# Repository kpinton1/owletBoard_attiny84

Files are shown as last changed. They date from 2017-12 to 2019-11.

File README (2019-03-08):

Readme

Documentation including BOM and bootloader instructions, component arrangement, and Users guide are located in documentation. 

PCB schematics and layout are in hardware(oregon) and hardware(owl)

Latest design files are fab_v3.zip for both Owl and Oregon shapes. 

We use Micronucleus bootloader which uses V-USB. License file included.

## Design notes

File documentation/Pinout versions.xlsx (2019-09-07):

Arduino Pin Number | OregonBoard v3 | owlBoard v5.0c | owlBoard v6 | OregonBoard v4 | Logic
0 | Right Eye LED | Right Eye LED | Portland Metro LED | Portland Metro LED | ‘1’ = ON; ‘0’ = OFF
1 | Switch 1 | Switch 1 | Switch 1 | Switch 1 | PUSHED = ‘1’; ELSE = ‘0’
2 | Switch 2 | Switch 2 | Switch 2 | Switch 2 | PUSHED = ‘1’; ELSE = ‘0’
3 | Red RGB | Pinout to header | Red RGB | Pinout to header | ‘0’ = ON; ‘1’ = OFF
4 | Blue RGB | Pinout to header | Blue RGB | Pinout to header | ‘0’ = ON; ‘1’ = OFF
5 | Green RGB | Pinout to header | Green RGB | Pinout to header | ‘0’ = ON; ‘1’ = OFF
6 | Pinout to header | Red RGB | Pinout to header | Red RGB | ‘0’ = ON; ‘1’ = OFF
7 | Pinout to header | Blue RGB | Pinout to header | Blue RGB | ‘0’ = ON; ‘1’ = OFF
8 | Pinout to header | Green RGB | Pinout to header | Green RGB | ‘0’ = ON; ‘1’ = OFF

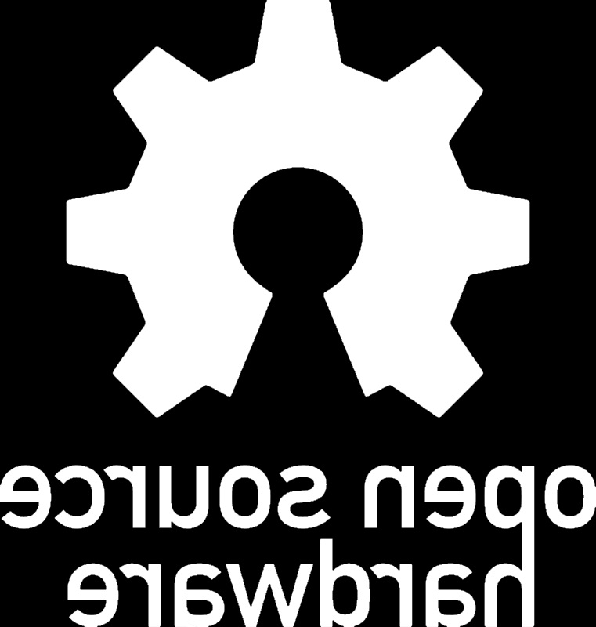
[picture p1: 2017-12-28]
images/bw_oshw.jpg

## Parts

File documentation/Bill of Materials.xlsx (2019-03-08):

Component | Footprint | Quantity | Reference Designator | Supplier | Vendor |  |  | Notes
RGB LED (Common Anode) | 5mm LED | 1 | D3 | Any 5mm Common Anode LED | Any | 0.1
LED (Always use red for Portland Metro LED) | 3mm LED | 2 | D1, D2 | Any 3mm LED | Any | 0.1
Linear regulator AMS1117-3.3 | SOT-223 | 1 | U3 | AMS1117-3.3 | Any | 0.1 |  | Can sub with LM1117-3.3 if need US supplier
Ceramic capacitor 1.0 UF | 5.08mm spacing | 2 | C1,C2 | Any 1uF ceramic with 5.08mm spacing | Any | 0.1
330 Ohm resistor | Through-hole | 5 | R1, R2, R12,R13,R14 | CF14JT330R | Stackpole | 0.1 | Digikey or Arrow
68 Ohm resistor | Through-hole | 2 | R8, R9 | CF14JT68R0TR | Stackpole | 0.1 | Digikey or Arrow
1.5K or 10K resistors | Through-hole | 3 | R4, R6, R7 | CF14JT10K0TR | Stackpole | 0.1 | Digikey or Arrow
USB connector type A (Owlboard Jr.) or type B (Oregon board) | Varies | 1 | J5/U4 | UJ2-BH-1-TH OR UP2-AH-1-TH | CUI | 0.54 | Digikey or Arrow | Use UJ2-BH for Oregon board Use UP2-AH-1-TH for Owl board
ATTINY84 Microcontroller | PDIP-14 | 1 | U1 | ATTINY84A-PU | Microchip | 0.99 | Digikey or Arrow | This part needs to be programmed!
Button | 6mm x 6mm | 2 | S1, S2 | 1825910-6 | TE Connectivity | 0.11 | Digikey or Arrow | Check for fit. Unsure.
Fuse | 1206 | 1 | Fuse | 0ZCH0020FF2E | Bel | 0.11 | Digikey or Arrow
USB A | N/A | 1 | N/A | Monoprice | Monoprice | 1.19 | Monoprice (https://www.monoprice.com/product?p_id=5438) | Use only for Oregon board

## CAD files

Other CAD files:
hardware(oregon)/Oregon_Outline2.dwg
hardware(oregon)/Oregon_Outline1.dwg
hardware(oregon)/Oregon_Outline3.dwg

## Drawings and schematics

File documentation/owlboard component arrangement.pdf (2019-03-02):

# Owlboard / Oregon Board Workshop

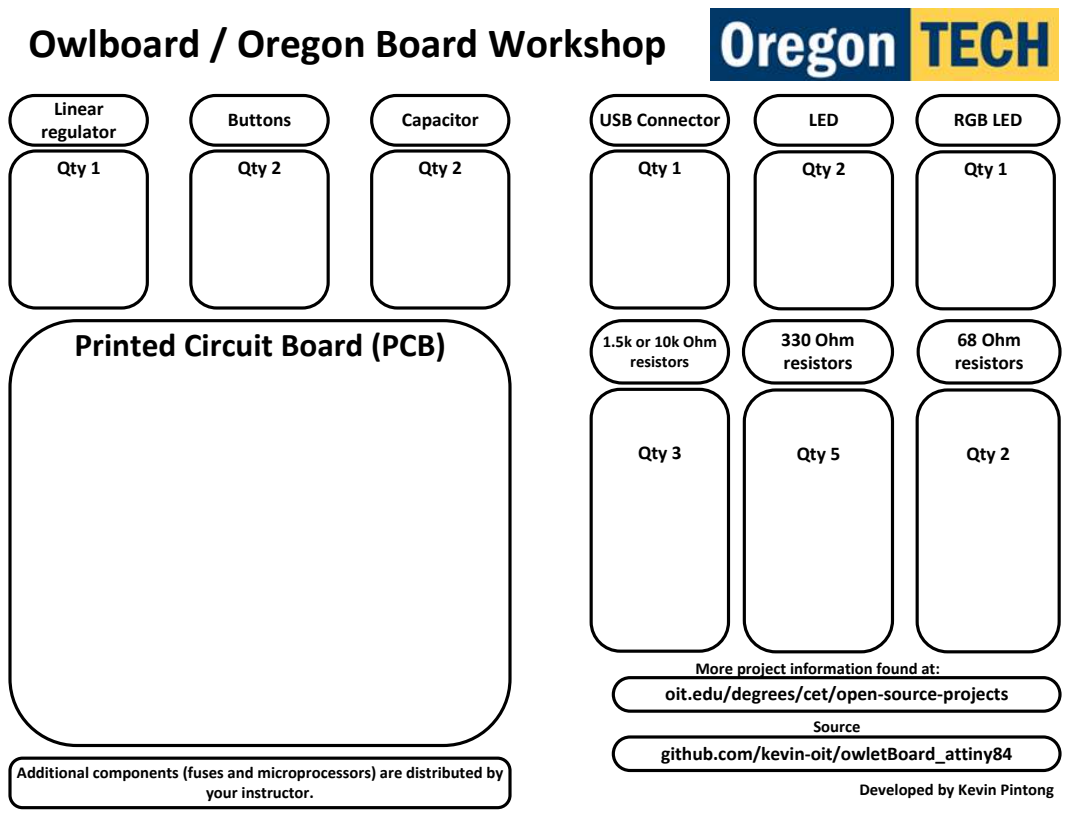
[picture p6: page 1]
Buttons; 1.5k or 10k Ohm; Qty 2; Qty 5; your instructor.; Developed by Kevin Pintong; 330 Ohm resistors; 68 Ohm resistors; Capacitor Linear; regulator; USB Connector; LED; RGB LED; Qty 1; Source; Qty 3

resistors Printed Circuit Board (PCB)

More project information found at:
oit.edu/degrees/cet/open-source-projects

github.com/kevin-oit/owletBoard_attiny84

Additional components (fuses and microprocessors) are distributed by

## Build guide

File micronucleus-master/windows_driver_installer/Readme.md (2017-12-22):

# Windows driver installation with Zadig #

Zadig is an automated windows driver installer for libusb devices. It will automatically create a driver signature, which prevents issues with unsigned drivers on Windows 10 and earlier. The latest version of Zadig can be found here: [http://zadig.akeo.ie/](http://zadig.akeo.ie/). For convenience, a copy is provided in this folder.

Please proceed as follows to install the Micronucleus driver:

1. Run Zadig_2.1.2.exe. The interface, as shown below, appears.
2. In the menu, go to *Device->Load Preset Device*.  Select micronucleus.cfg.
3. Click the "Install Driver" button.

The driver is now installed and Micronucleus should be ready to use. 

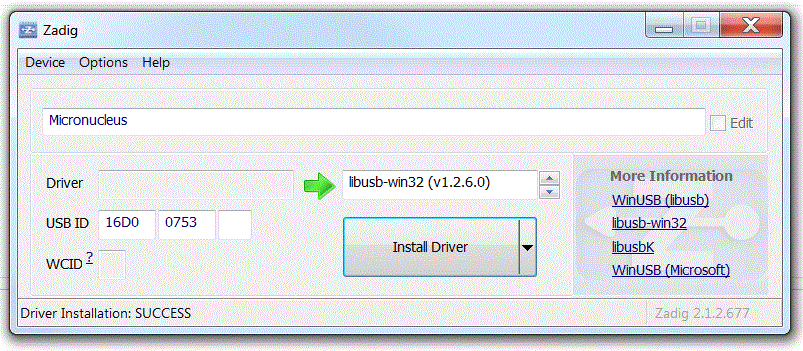
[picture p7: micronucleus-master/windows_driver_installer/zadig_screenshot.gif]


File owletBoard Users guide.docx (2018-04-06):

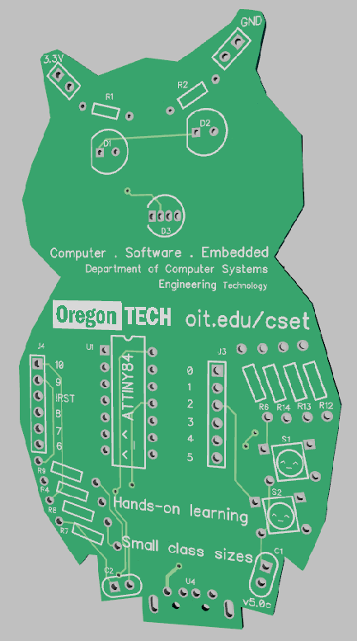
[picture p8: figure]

Oregon Institute of Technology

Owlboard Jr. v4.0 / Oregon shape board v1.0

Users Guide / Assembly Guide / Tutorials

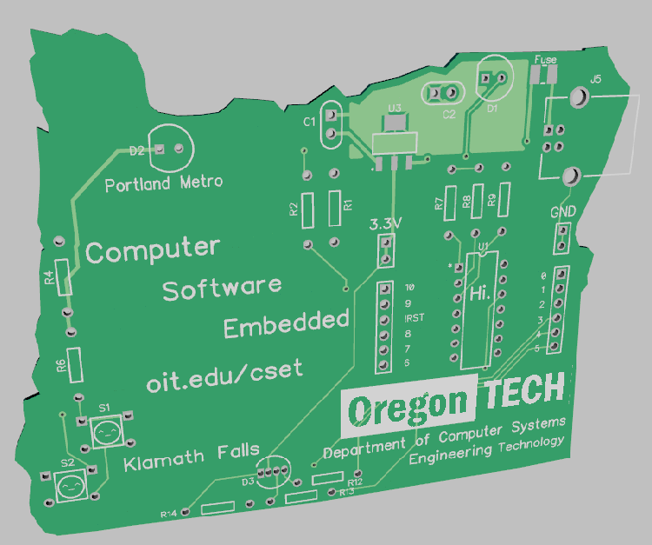
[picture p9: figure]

# Note

Portions of software and hardware design originated from Digispark, a product of Digistump. The Owlboard Jr. and Oregon Shape board are not products of Digistump. Do not contact them for any support.

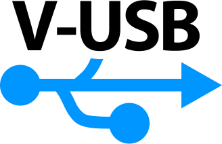
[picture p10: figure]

The USB bootloader uses V-USB, available from: https://www.obdev.at/products/vusb/index.html

# Safety and Liability

If you are participating in the soldering portion of the workshop, you must do the following:

1) Listen to and follow instructions from faculty and student assistants.
2) Wear personal protective equipment such as safety glasses.
3) Use the fume extractor to blow smoke away from you.
4) Be aware that the soldering iron is hot, and you should be careful when using it.
5) Be aware that the flux and solder fumes, while not hazardous can cause respiratory distress.
6) Wash your hands after the workshop and after handling your board.

Be aware that you are putting together a board which may be plugged into your computer. While the faculty and student assistants involved will try and make sure that the board is properly assembled, note that improperly assembled boards or improperly handled boards may cause damage to your computer.

Oregon Institute of Technology is not responsible for any damage to your personal computer.

# Owlboard Jr. v4.0 and Oregon board v1.0 Features

The owlboard Jr. and Oregon board are community outreach boards designed at Oregon Tech. They are open sourced boards using the VUSB bootloader. The software and hardware are available at the link below.

https://github.com/kevin-oit/owletBoard_attiny84

Features of the Owlboard Jr v4.0 / Oregon board v1.0

- ATTINY84 microprocessor in dip package
- One 3mm LED
- One 5mm RGB LED
- Two push buttons
- Integrated USB bootloader (V-USB)
- Built-in USB connector on Owlboard Jr.
- USB-B connector on Oregon board v1.0
- 350 mA poly fuse
- 3.3 V System voltage

ADD PICTURE OF OWLBOARD and OREGON board

# Circuit and component primer

# Assembly Instructions

Add schematic and bill of materials

# Board setup – Buttons, LEDs, and pin locations

When writing code for the Owlboard Jr. or Oregon shaped board, please use the pin numbers below in Arduino IDE.

Arduino Pin Number | Owlboard Jr. | Oregon shaped board | Logic
0 | Right Eye LED | Portland Metro LED | ‘1’ = ON; ‘0’ = OFF
1 | Switch 1 | Switch 1 | PUSHED = ‘1’; ELSE = ‘0’
2 | Switch 2 | Switch 2 | PUSHED = ‘1’; ELSE = ‘0’
3 | Red RGB | Red RGB | ‘0’ = ON; ‘1’ = OFF
4 | Blue RGB | Blue RGB | ‘0’ = ON; ‘1’ = OFF
5 | Green RGB | Green RGB | ‘0’ = ON; ‘1’ = OFF
6 | Pinout to header
7 | Pinout to header
8 | Pinout to header
9 | Pinout to header
10 | Pinout to header

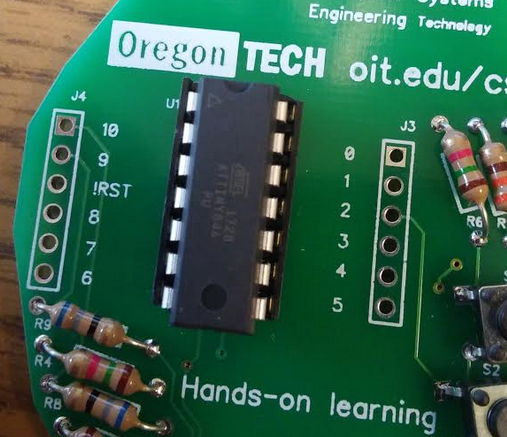
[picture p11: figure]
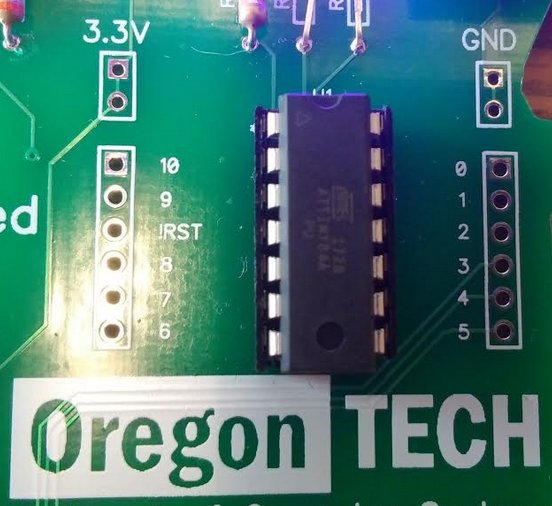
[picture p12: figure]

For example, if you wish to turn the Portland Metro or Right Eye LED on, you would need to:

1) Set pin 0 to an output

pinMode(0, OUTPUT);

2) Write in the loop logic ‘1’.

digitalWrite(0,HIGH);

If you wish to configure the button S1, you would need to:

1) Set switch 1 to input

pinMode(1, INPUT);

2) Read the button

digitalRead(1);

# Pinout of ATTINY84

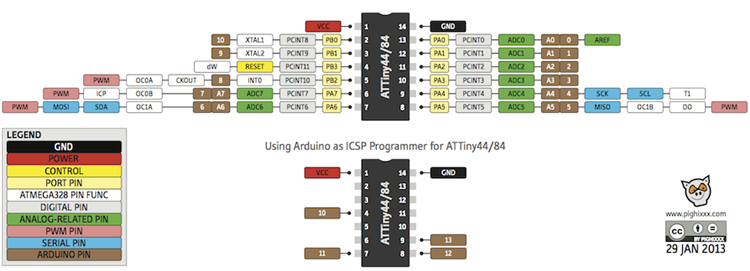
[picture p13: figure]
ATtiny84 and ATtiny84a pinout

# Installation

1. Install Arduino IDE from this link: https://www.arduino.cc/en/Main/Software
2. After Arduino IDE is installed, launch Arduino IDE.
3. Go to File > Preferences.

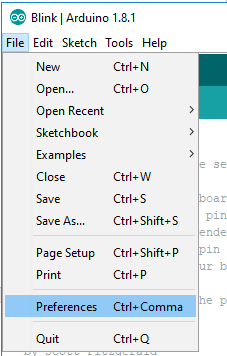
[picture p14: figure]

4. You should see the following screen.

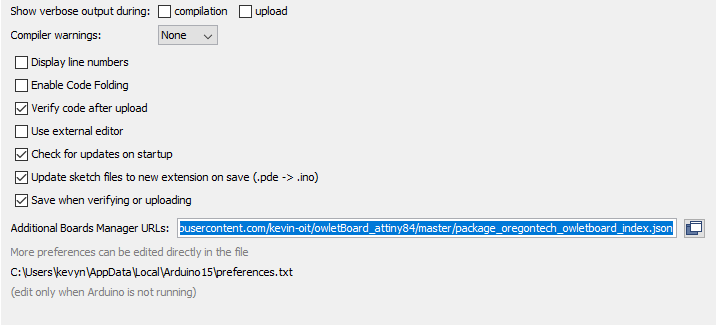
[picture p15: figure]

5. Under Additional Boards Manager URL paste this: https://raw.githubusercontent.com/kevin-oit/owletBoard_attiny84/master/package_oregontech_owletboard_index.json
6. Click OK.
7. Go to Tools > Boards > Board Manager

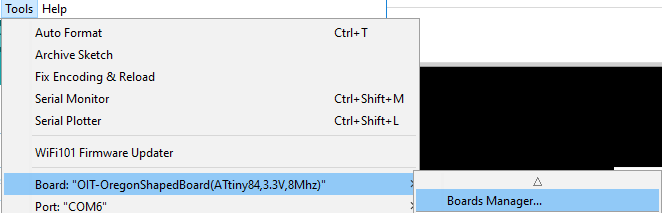
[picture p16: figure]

8. Type owl into the menu bar and you should see owlet Boards by owletBoard. Click install.
9. Download this file:

https://github.com/kevin-oit/owletBoard_attiny84/blob/master/micronucleus_for_owlboard_0.1-win.zip

10. Unzip the file.

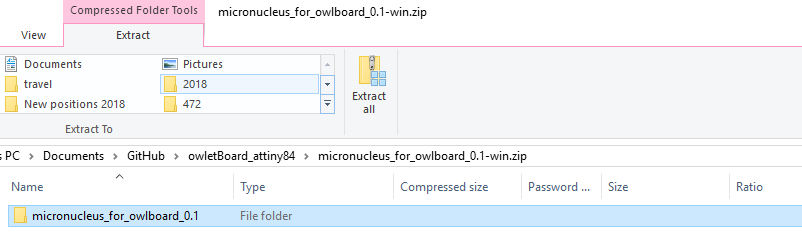
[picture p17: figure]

11. When the files are extracted, a new window will open up.
12. Navigate to the windows_driver_installer folder.
13. Double-click on zadig_2.1.2.exe. The window below should launch.

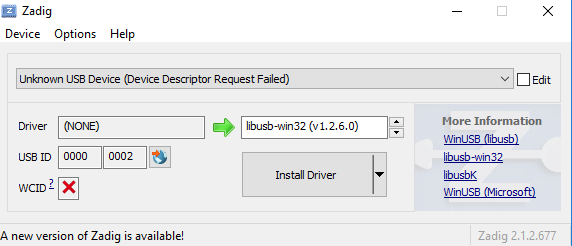
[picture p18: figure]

14. Plug your board into the computer. Within 5 seconds, switch to the unknown device and then click Install Driver. You may need to try more than once to install the driver.
15. Wait for success.

Congratulations.

You have now installed all the software required to use the Owlboard Jr. or the Oregon shape board.

# Tutorial 1: Uploading code to the board

1. Make sure you have installed the driver, Arduino IDE, and installed the board file as listed in the previous section.
2. Launch Arduino IDE

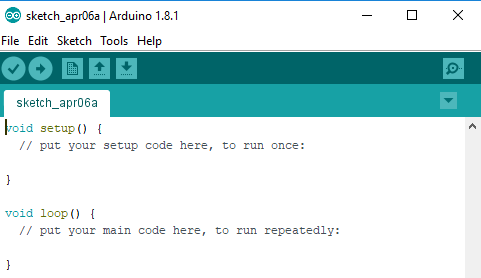
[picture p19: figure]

3. We’ll need something to program to the board, so navigate to the basic example.

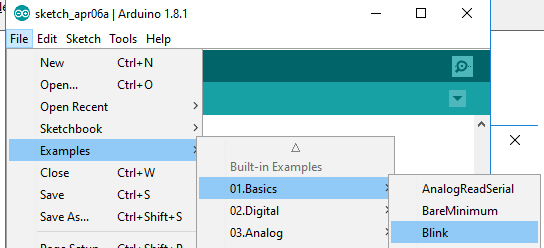
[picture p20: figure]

4. The basic example should open.

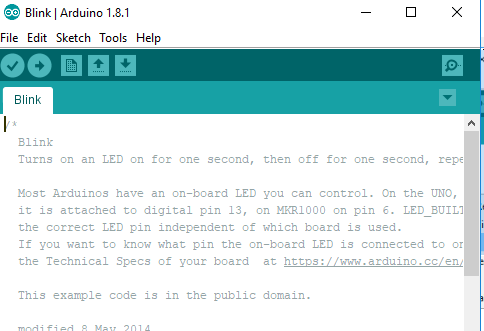
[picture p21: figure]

5. The basic example needs to be modified, because one of the LEDs on the Owlboard Jr. or Oregon board is set to pin 0. Add the line of code shown below.

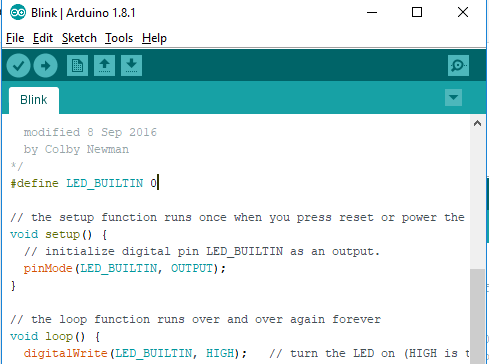
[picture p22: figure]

6. Click on the owletBoard or OIT-OregonShapedBoard, depending on which board you have.

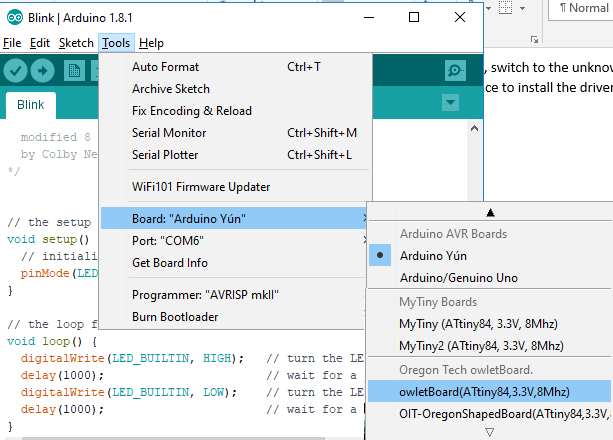
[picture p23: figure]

7. Make sure that the bottom lower right corner indicates that the correct board, owletBoard or OIT-OregonShapedBoard is selected.

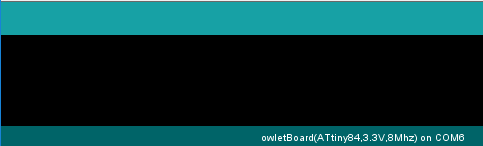
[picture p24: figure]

8. Click the arrow button. This will compile and upload your code to the board. Note that it will ask you to plug in the device (‘Running Digispark Uploader… Plug in device now…). You must unplug and replug the device within 60 seconds or the system will timeout.

If the timeout occurs, press the arrow button again, remembering plug in the board when asked.

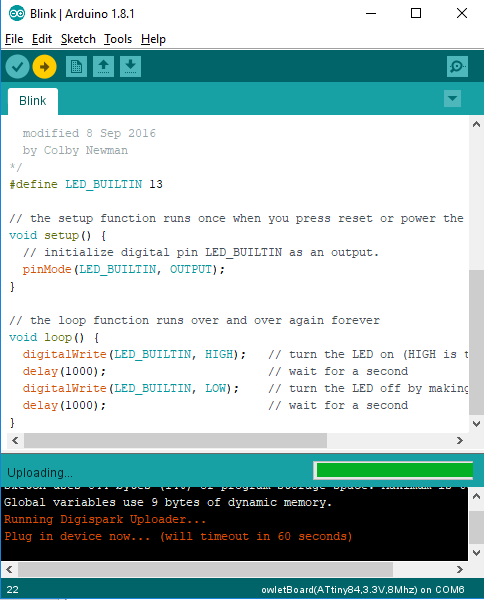
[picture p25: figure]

9. If it is successful you should see the following in the box below.

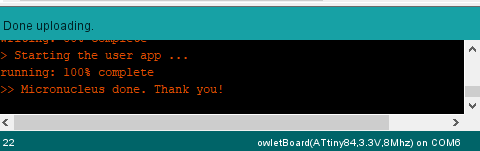
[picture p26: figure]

10. On the Owlboard Jr, the right eye should now blink. On the Oregon shape board, the Portland Metro LED should now blink.

Tutorial: Blinking an LED

Tutorial on an example of how to blink it faster or slower. What about different on or off times?

# How to configure the button to turn on the LED

# How to configure the button to toggle the LED

# How to turn on the RGB LED?

# How to use the button to change the colour of the RGB LED?

# How to PWM the RGB LED?

More information

Make sure explain user this not normal Arduino, may need use different pins. This device have limited memory and MHz. Can try digistump libraries included but not guarantee to work.

How to program

1. Press the compile and upload button
2. Plug in digispark when asked to do so
  a. Make sure to disclaim all legal liability.
3. Windows will error with USB device but is ok.

Use material from:

From https://digistump.com/wiki/digispark/tutorials/connecting

and https://learn.sparkfun.com/tutorials/how-to-install-an-attiny-bootloader-with-virtual-usb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

to fill in the rest.

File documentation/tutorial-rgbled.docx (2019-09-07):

Tutorial: Using the RGB LED

The RGB LED is actually three LEDs in one package. In order to manipulate each of the LEDs into turning on or off, we will need to setup some basic information below.

1. Open a new Arduino file. File > New
2. We need to define the RGB LEDs. The code should go at the beginning of the file.
  a. To define the RGB LED, add the following lines of code. Red is on pin 8, Blue is on pin 7, and Green is on pin 6.

#define RED 8

#define BLUE 7

#define GREEN 6

3. We need to setup the RGB LEDs are outputs. The code should be written in the setup() section.
  a. For each LED, you need to use the LED name and write the following line.

pinMode(RED, OUTPUT); // RED is connected to pin 8. It is now configured as output.

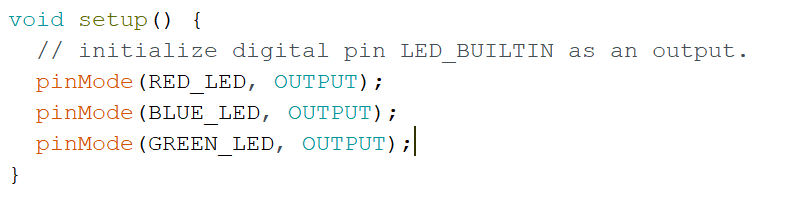
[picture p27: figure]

4. Now, we need to run code in the loop(). Code placed in this section will run over and over.
  a. Use the digitalWrite function.

digitalWrite(GREEN, HIGH); //Turn GREEN LED off

digitalWrite(GREEN,LOW);//Turn GREEN LED off

digitalWrite(NAME , MODE)

NAME – We defined it as RED, GREEN, or BLUE.

MODE – This can be HIGH or LOW.

  b. Use the delay function.

delay(500); //Delay for half a second.

delay(TIME)

TIME – This is the time. 1000 = 1 second.

  c. Look for the loop() section of code.
5. Let’s try to turn the RED led on and off every half second. Use the following code.

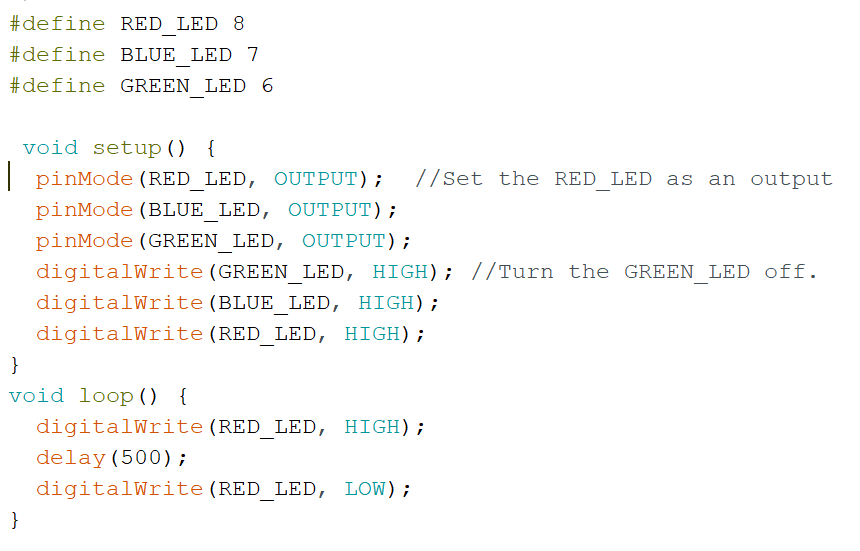
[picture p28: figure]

6. Use the regular programming procedure.
  a. Unplug the board and hit the arrow circled in red. Make sure that the owlBoard shows up under the lower right corner.
  b. Press the right arrow boxed in red below.

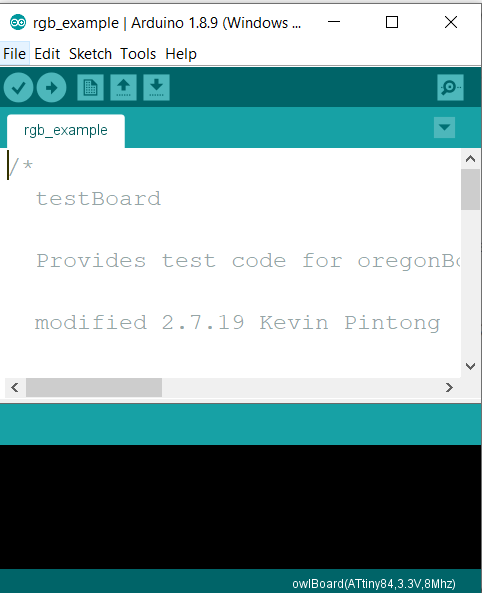
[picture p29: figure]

Challenge 1: Make sure you can blink the RED led.

Challenge 2: Try blinking the GREEN led or BLUE led.

Challenge 3: Make the RGB led blink in order: Red, Green and then Blue.

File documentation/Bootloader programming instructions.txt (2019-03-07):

Copy of firmware is in micronucleus-master/firmware/releases

Use program.bat from firmware/releases folder, making sure avrdude and usbasp are installed first. (zadig and winavr)

avrdude -c usbasp -p t84 -P usb -b 19200 -U flash:w:t84_default.hex 

avrdude -c usbasp -p t84 -P usb -b 19200 -U lfuse:w:0xe2:m -U hfuse:w:0xdd:m -U efuse:w:0xfe:m

avrdude -c usbasp -p t84 -P usb -b 19200 -U lfuse:r:-:i

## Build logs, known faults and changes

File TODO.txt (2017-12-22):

Known problems

1. The included library files are bad. Have someone go through and check that at a minimum the following work:
a. LED blink
b. RGB example
c. SoftSerial (Need to get rid of leonardo code and lower speed to 9600)
d. SPI
e. WS2811
f. OneWire 
g. Softpwm on LED
h. Test the rest of them to see if compile mark any that don't work.

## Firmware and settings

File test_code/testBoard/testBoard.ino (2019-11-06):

/*
  testBoard 

  Provides test code for oregonBoard and owlBoard
  
  modified 2.7.19 Kevin Pintong 

  Test disposition:
  1) The board should blink the portland metro or right owl eye at a rate of 1 second. 
  2) The RGB LED should cycle through Red, Blue, and Green
  3) When S1 is pressed, all lights should turn off except the left eye or right power indicator. 
  4) When S2 is pressed, all lights should turn on. 
  
  This example code is in the public domain.

*/

#define LED_BUILTIN 0
#define BTN1 1
#define BTN2 2
#define v7
#ifdef v7
#define RED_LED 8 
#define BLUE_LED 7
#define GREEN_LED 6
#endif 

#ifndef v7
#define RED_LED 3
#define BLUE_LED 4
#define GREEN_LED 5
#endif
int btn1State = 0;
int btn2State = 0;
// the setup function runs once when you press reset or power the board
void setup() {
  // initialize digital pin LED_BUILTIN as an output.
  pinMode(LED_BUILTIN, OUTPUT);
  pinMode(RED_LED, OUTPUT);
  pinMode(BLUE_LED, OUTPUT);
  pinMode(GREEN_LED, OUTPUT);
  pinMode(BTN1, INPUT);
  pinMode(BTN2, INPUT);
  digitalWrite(GREEN_LED, HIGH);
  digitalWrite(BLUE_LED, HIGH);
  digitalWrite(RED_LED, HIGH);
}

// the loop function runs over and over again forever
void loop() {

  digitalWrite(LED_BUILTIN, HIGH);   // turn the LED on (HIGH is the voltage level)
  delay(1000);                       // wait for a second
  digitalWrite(LED_BUILTIN, LOW);    // turn the LED off by making the voltage LOW
  delay(1000);                       // wait for a second
  digitalWrite(GREEN_LED, LOW);
  digitalWrite(BLUE_LED, HIGH);
  digitalWrite(RED_LED, HIGH);
  delay(1000);
  digitalWrite(GREEN_LED, HIGH);
  digitalWrite(BLUE_LED, LOW);
  digitalWrite(RED_LED, HIGH);
  delay(1000);
  digitalWrite(GREEN_LED, HIGH);
  digitalWrite(BLUE_LED, HIGH);
  digitalWrite(RED_LED, LOW);
  delay(1000);
  btn1State = digitalRead(BTN1);
  btn2State = digitalRead(BTN2);

  if(btn1State == LOW){            //Test S1- If pressed, should turn off everything for 3 seconds
    digitalWrite(GREEN_LED, HIGH);
    digitalWrite(BLUE_LED, HIGH);
    digitalWrite(RED_LED, HIGH);
    digitalWrite(LED_BUILTIN, LOW);
    delay(5000);
  }
  if(btn2State == LOW){            //Test S2- If pressed, should turn on everything for 3 seconds
    digitalWrite(GREEN_LED, LOW);
    digitalWrite(BLUE_LED, LOW);
    digitalWrite(RED_LED, LOW);
    digitalWrite(LED_BUILTIN, HIGH);
    delay(5000);
  }
}

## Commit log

2017-12-22 Add initial
    [micronucleus.cfg]
2017-12-22 add board files
2017-12-22 Change name for micronucleus and remove digispark name
    [micronucleus.cfg]
2017-12-22 Wrong board.txt description
2017-12-22 Upload initial hardware design
    Initial schematic and layout
2017-12-22 More updates on PCB
    update layout
2017-12-28 Finalized design
    [Oregon_Outline1.dwg, Oregon_Outline2.dwg, Oregon_Outline3.dwg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]
2018-01-07 Updated to use arduino library instead.
2018-01-07 Wrong zip file, wrong text
    Wrong board description and wrong zip file.
2018-01-07 Wrong board name
    Wrong board name
2018-01-07 Fix naming
    Fix . instead of :, board name not liked
2018-01-07 PCB Design change
    Update silk to move away from vias, add heat dissipation on regulators, and switch out buttons for correct size.
2018-04-06 New FAB and user guide.
    New FAB and user guide.
    [BoardOutline.gbr, Bottom.gbr, BottomMask.gbr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]
2019-03-02 Update
    Cleanup files
    [BoardOutline.gbr, Bottom.gbr, BottomMask.gbr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]
2019-03-08 Update PCB design
    Enlarge footprints for SOT223, RGB, and FUSE. Add programmer header in case chips are not programmed properly. Rearranged spacing.
    [Bill of Materials.xlsx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]
2019-03-13 Change RGB
    RGB pins changed to PWM on pin 5,6,7 on both boards
    [BoardOutline.gbr, Bottom.gbr, BottomAssy.gbr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]
2019-03-19 Updated to v6 gerbers
    [BoardOutline.gbr, Bottom.gbr, BottomAssy.gbr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]
2019-03-19 Update the ipc version of board with new silk
    [BoardOutline.gbr, Bottom.gbr, BottomAssy.gbr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]
2019-07-02 Updated guide for new boards and provide test code
    Uploaded test code and updated user guide.
    [Pinout versions.xlsx]
2019-09-07 New shape
    [BoardOutline.gbr, Bottom.gbr, BottomAssy.gbr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]
2019-10-11 Updated for footprint improvements per Chicago
    [BoardOutline.gbr, Bottom.gbr, BottomMask.gbr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]
2019-10-12 Improve solderability
    [BoardOutline.gbr, Bottom.gbr, BottomAssy.gbr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]
